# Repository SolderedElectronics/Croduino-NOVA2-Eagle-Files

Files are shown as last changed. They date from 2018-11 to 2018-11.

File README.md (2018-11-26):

# Croduino NOVA2 Eagle Files
## Image
Croduino NOVA2 image
[Croduino NOVA(222067)](https://e-radionica.com/en/croduino-nova2.html)

## Description and details
The Croduino NOVA2 is a microcontroller board with the ability to connect to a WiFi network and the Internet! It is based on an already well-known ESP8266 which is otherwise quite complicated to use on its own. With Nova, simply connect the board to USB and start programming your next IoT project. In addition, the microcontroller boards ideally suited for breadboard, which makes prototyping is even faster. Connecting the physical world with the internet has never been easier.

The brain of these boards is already mentioned Espressif's ESP826. Comes with full WiFi (both client and server side) and an integrated TCP / IP stack that supports DNS! Most importantly - programmable from Arduino IDE, there is no need to manually reset the board. The 80MHz frequency processor has as much as 1MB of space for your code (0.8MB available, bootloader 0.2MB) and 82kB of RAM (of which you can use 49kB). The board supports I2C, SPI and serial communications and has 9 GPIO pins, all of which support PWM and one analog input. In addition to the above, the board uses CH340 as a USB 2.0 interface, 3.3V voltage regulator, 4 LEDs, FCC and CE certificate, and a lot more. There is also an easyC connector on the board, which allows easy connection of various devices (available in e-radionica's offer) with a board. Finally, there is a standard JST lithium-ion connector for your project to be truly wireless. When you need to charge a battery, just plug in the USB cable and charge the battery with the integrated charger on the board. In detail:

- ESP8266 in ESP-12 package
- 80MHz, 1MB flash, 82kB RAM
- programmable from Arduina!
- 9 GPIO pins of which all support PWM
- 1 analog input(ADC), max. voltage 1V i 5V
- I2C, SPI, serial communication
- CH340 USB to UART bridge with micro USB connector
- 3.3V voltage regulator
- LEDs: power, tx, rx, GPIO13
- automatical hardware reset before upload of code
- two pushbuttons: reset i GPIO0
- comes with micro USB cable
- FCC i CE certificates for ESP-12

ESP8266 on-board is loaded with default bootloader.

## Repository content
This repo contains Cadsoft Eagle .sch and .brd files for Croduino NOVA board. It also contains schematic in .pdf created from .sch Eagle file. 
Files have been arranged into folders for navigating between different versions of board. 
Tip: layer 200 shows top silkscreen and layer 208 should be bottom silkscreen. tParts and bParts layers are not used.

## Docs
- [Croduino NOVA 2product page] (https://e-radionica.com/en/croduino-nova2.html)

## Board versions
- v1.0 - inital published version 

## License info
This product is open-source. Yay!
For any tech questions, contact us at techsupport@e-radionica.com
If you find an Issue, please open one at GitHub. If you can improve our product, fork us.

e-radionica.com Team.

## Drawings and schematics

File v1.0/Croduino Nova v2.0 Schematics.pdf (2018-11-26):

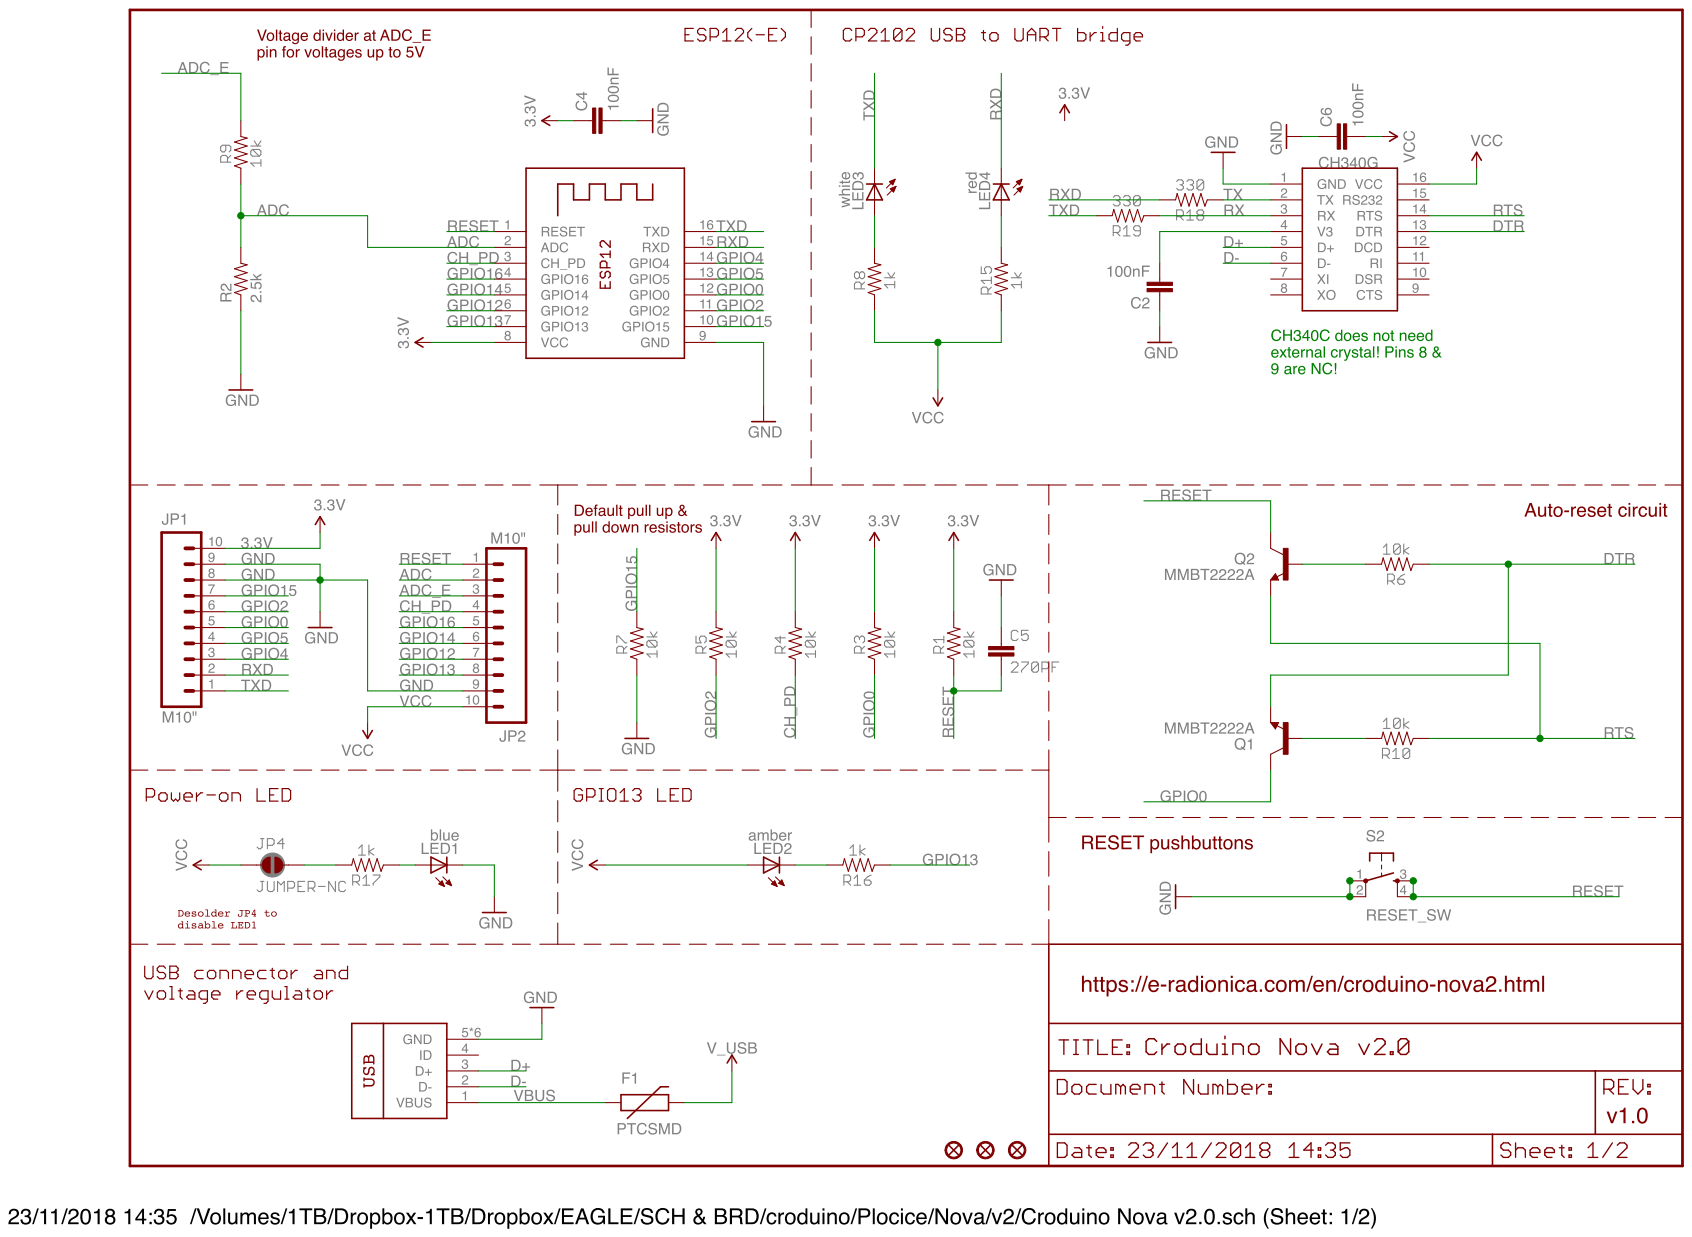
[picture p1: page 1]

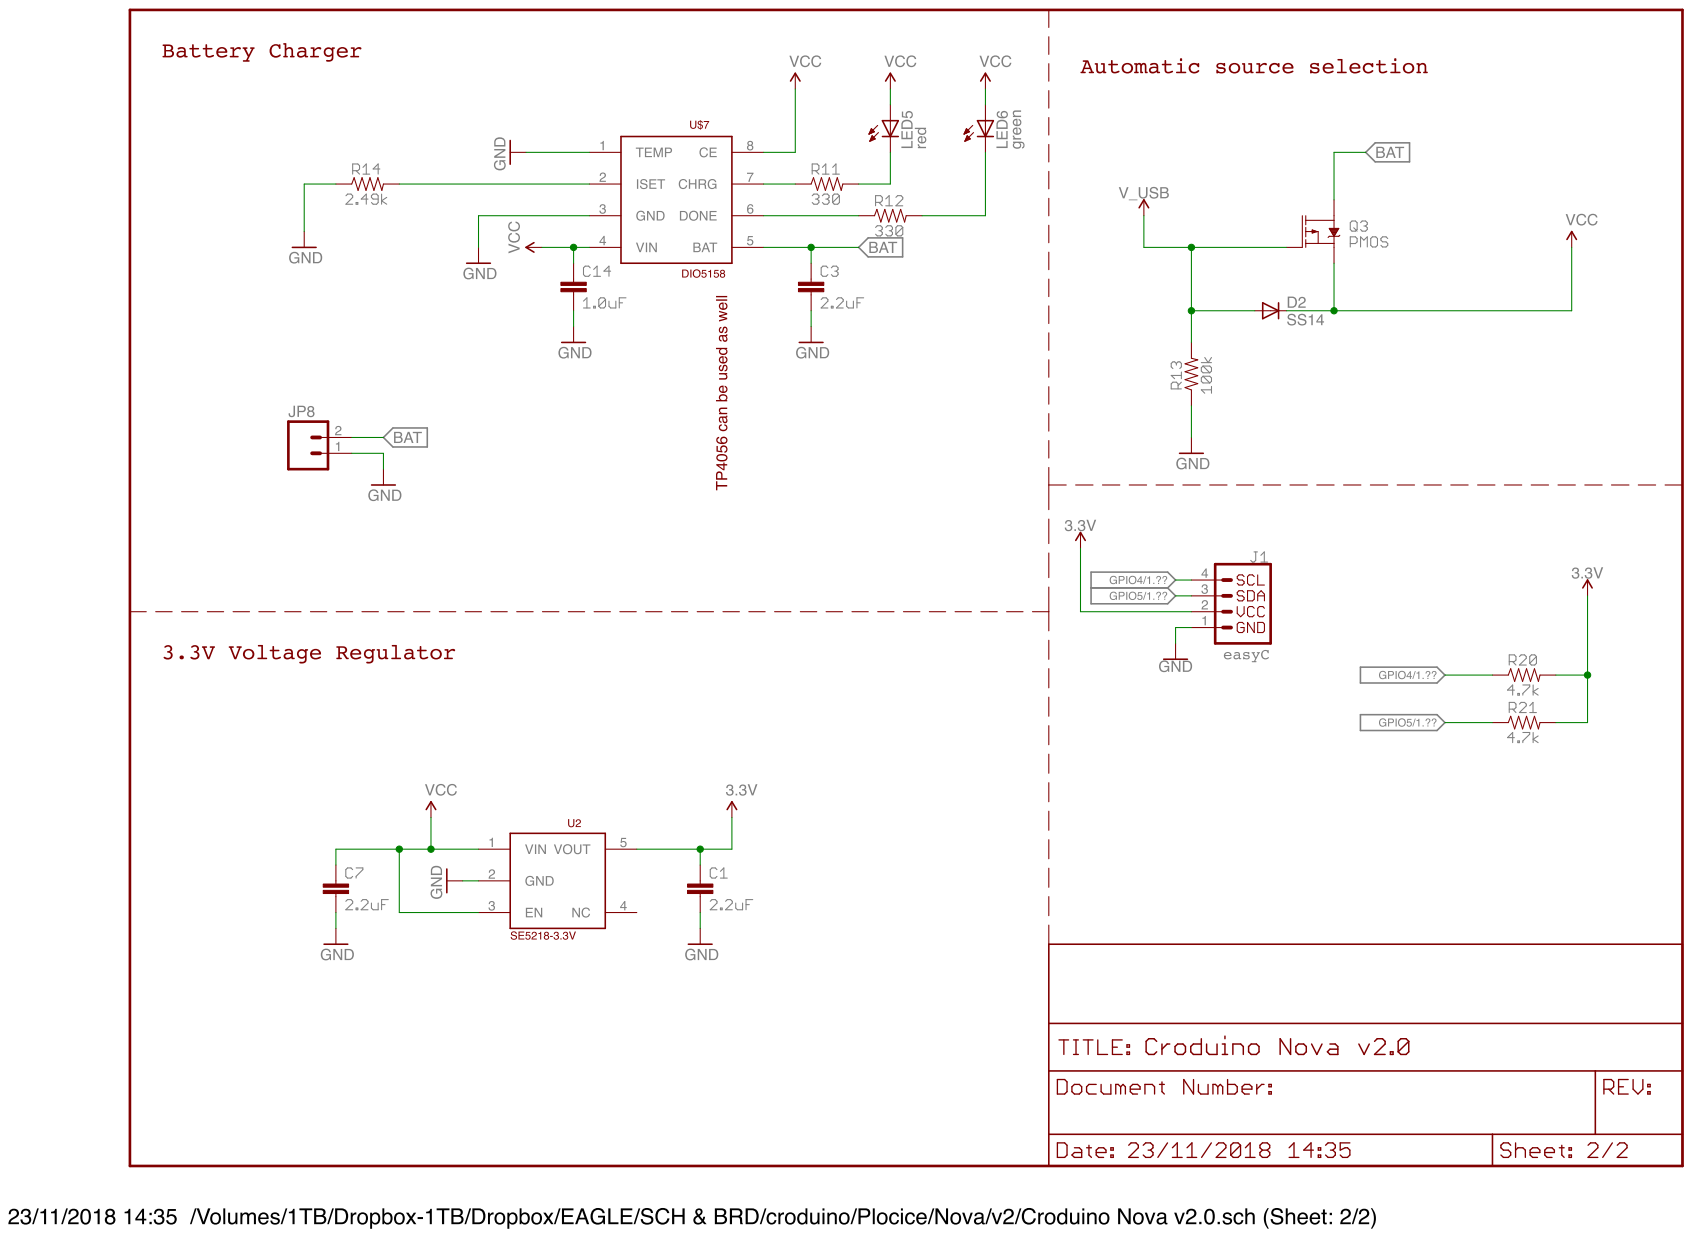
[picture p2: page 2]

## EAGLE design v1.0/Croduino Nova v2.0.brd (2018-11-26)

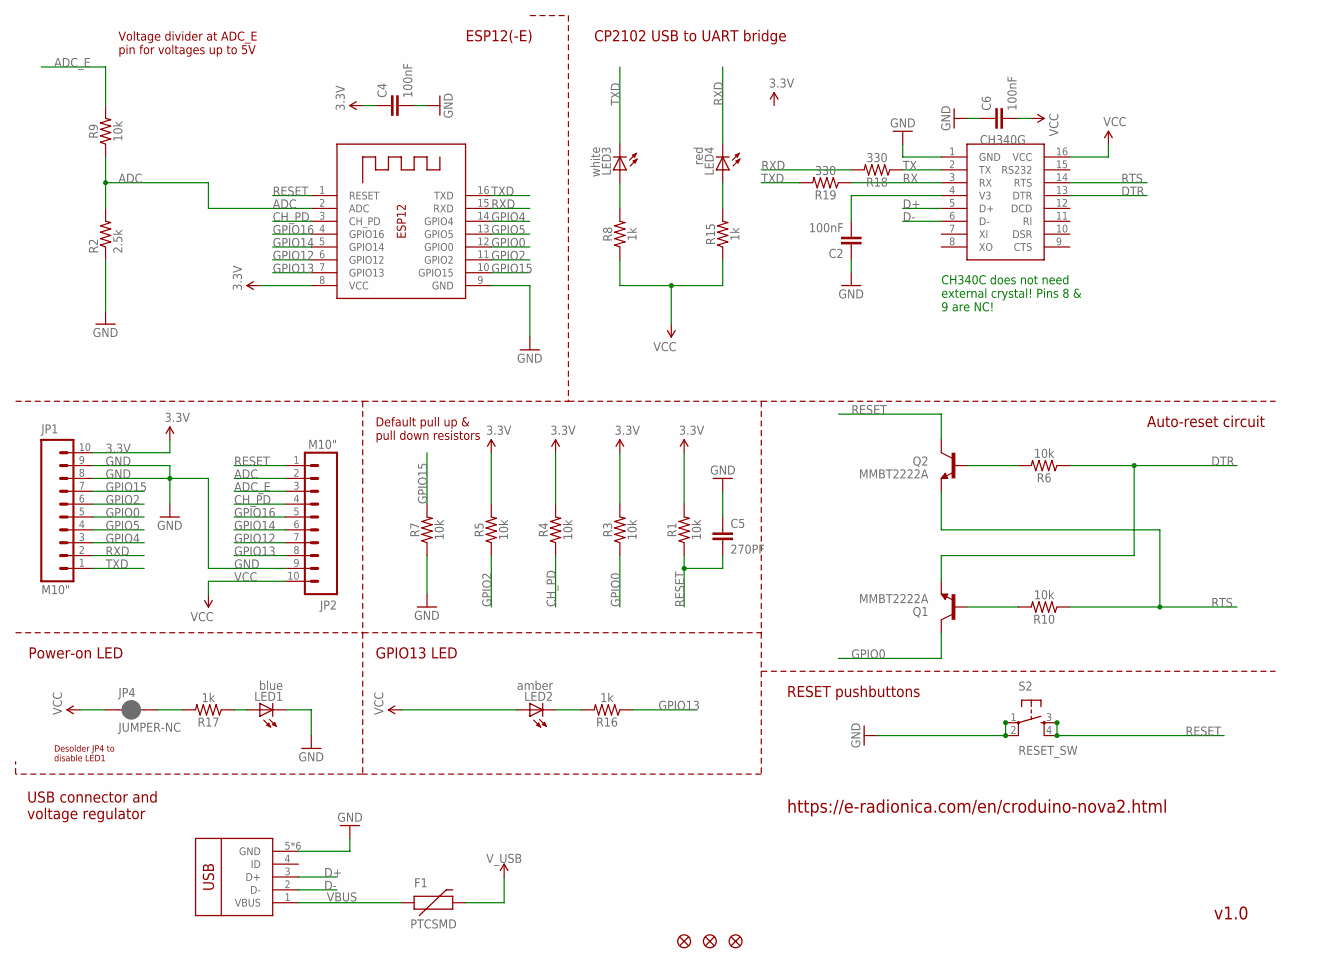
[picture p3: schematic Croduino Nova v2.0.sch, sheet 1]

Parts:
C2, C4, C6: 100nF; 0603-CAP
C5: 270PF; 0603
F1: PTCSMD; PTC-1206
JP1, JP2: M10"; 1X10
JP3, JP5, JP6: FIDUCIAL1X2; FIDUCIAL-1X2
JP4: JUMPER-NC; SMT-JUMPER_2_NC_PASTE_NO-SILK
LED1: blue; CHIP-LED0805
LED2: amber; CHIP-LED0805
LED3: white; CHIP-LED0805
LED4: red; CHIP-LED0805
Q1, Q2: MMBT2222A; SOT23-3
R1, R3, R4, R5, R6, R7, R9, R10: 10k; 0603
R2: 2.5k; 0603-RES
R8, R15, R16, R17: 1k; 0603
R18, R19: 330; 0603
S2: RESET_SW; TACTILE_SWITCH_SMD
U$8: USB-MICRO; U-F-M5DD-Y-L
U$10: CH340C; SOIC16
X1: ESP8266-12; ESP-12

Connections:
3.3V: C4.1, JP1.10, R1.2, R3.2, R4.2, R5.2, X1.8 (VCC); also elsewhere on the board
ADC: JP2.2, R2.2, R9.1, X1.2 (ADC)
ADC_E: JP2.3, R9.2
CH_PD: JP2.4, R4.1, X1.3 (CH_PD)
D+: U$8.3 (D+), U$10.5 (D+)
D-: U$8.2 (D-), U$10.6 (D-)
DTR: Q1.2 (E), R6.1, U$10.13 (DTR)
GND: C2.1, C4.2, C5.1, C6.1, JP1.8, JP1.9, JP2.9, LED1.C, R2.1, R7.1, S2.1, S2.2, U$8.5 (GND), U$8.PAD (GND), U$8.SHIELD1 (GND), U$8.SHIELD2 (GND), U$8.SHIELD3 (GND), U$8.SHIELD4 (GND), U$10.1 (GND), X1.9 (GND); also elsewhere on the board
GPIO0: JP1.5, Q1.3 (C), R3.1, X1.12 (GPIO0)
GPIO2: JP1.6, R5.1, X1.11 (GPIO2)
GPIO4: JP1.3, X1.14 (GPIO4); also elsewhere on the board
GPIO5: JP1.4, X1.13 (GPIO5); also elsewhere on the board
GPIO12: JP2.7, X1.6 (GPIO12)
GPIO13: JP2.8, R16.1, X1.7 (GPIO13)
GPIO14: JP2.6, X1.5 (GPIO14)
GPIO15: JP1.7, R7.2, X1.10 (GPIO15)
GPIO16: JP2.5, X1.4 (GPIO16)
unnamed: LED3.A, R8.2
unnamed: JP4.2, R17.2
unnamed: LED1.A, R17.1
unnamed: LED4.A, R15.2
unnamed: LED2.C, R16.2
unnamed: C2.2, U$10.4 (V3)
unnamed: Q1.1 (B), R10.2
unnamed: Q2.1 (B), R6.2
RESET: C5.2, JP2.1, Q2.3 (C), R1.1, S2.3, S2.4, X1.1 (RESET)
RTS: Q2.2 (E), R10.1, U$10.14 (RTS)
RX: R19.1, U$10.3 (RX)
RXD: JP1.2, LED4.C, R18.2, X1.15 (RXD)
TX: R18.1, U$10.2 (TX)
TXD: JP1.1, LED3.C, R19.2, X1.16 (TXD)
VBUS: F1.1, U$8.1 (VBUS)
VCC: C6.2, JP2.10, JP4.1, LED2.A, R8.1, R15.1, U$10.16 (VCC); also elsewhere on the board
V_USB: F1.2; also elsewhere on the board

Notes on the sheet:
USB connector and voltage regulator
Power-on LED
GPIO13 LED
Desolder JP4 to disable LED1
ESP12(-E)
CP2102 USB to UART bridge
Voltage divider at ADC_E pin for voltages up to 5V
Default pull up & pull down resistors
Auto-reset circuit
RESET pushbuttons
https://e-radionica.com/en/croduino-nova2.html
v1.0
CH340C does not need external crystal! Pins 8 & 9 are NC!

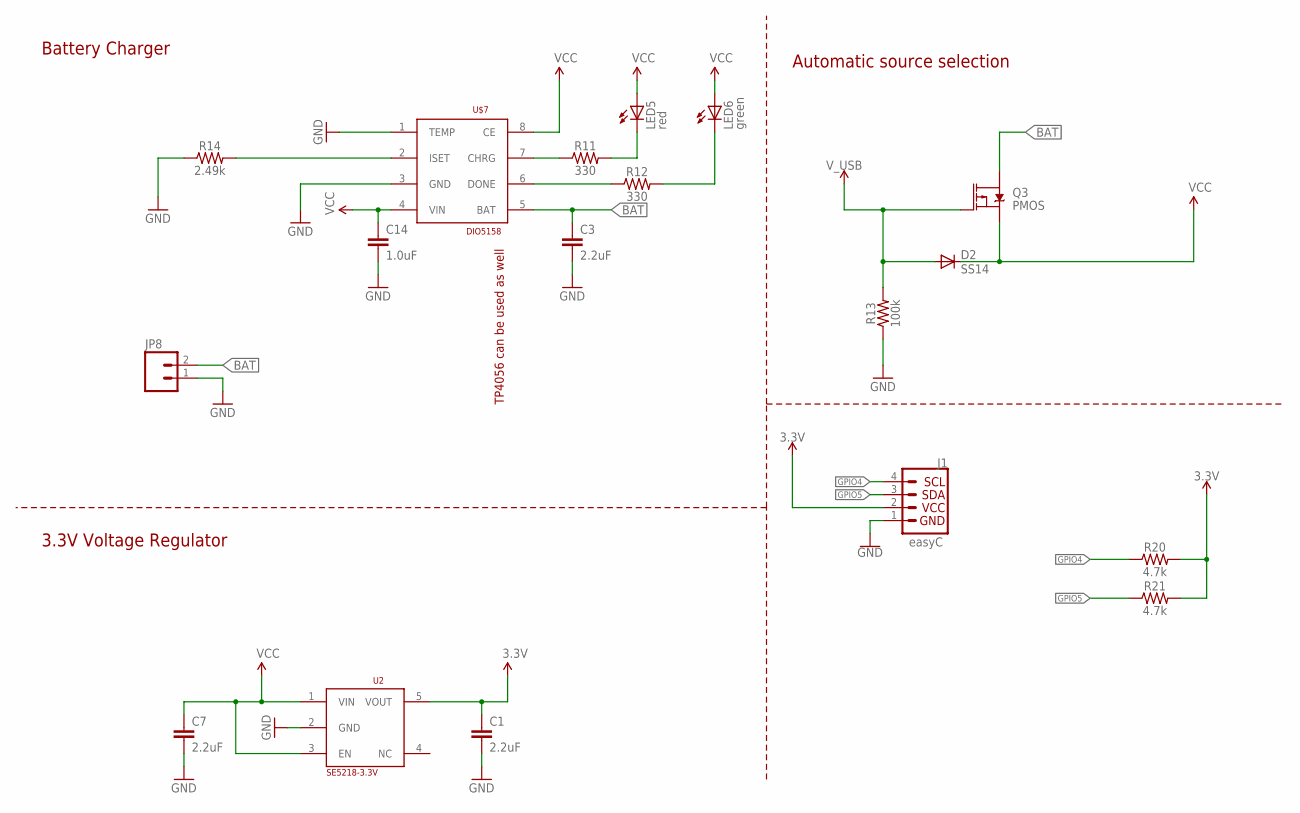
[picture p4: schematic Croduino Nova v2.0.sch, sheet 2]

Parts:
C1, C3, C7: 2.2uF; 0603
C14: 1.0uF; 0603
D2: SS14; DO-214AC
J1: QWIIC_CONNECTORJS-1MM; 1X04_1MM_RA
JP8: M02-JST-2MM-SMT; JST-2-SMD
LED5: red; CHIP-LED0805
LED6: green; CHIP-LED0805
Q3: PMOS; SOT23-3
R11, R12: 330; 0603
R13: 100k; 0603
R14: 2.49k; 0603
R20, R21: 4.7k; 0603
U2: SE5218-3.3V; SOT23-5
U$7: DIO5158; SOIC-8

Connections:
3.3V: C1.1, J1.2, R20.2, R21.2, U2.5 (VOUT); also elsewhere on the board
BAT: C3.1, JP8.2, Q3.3 (D), U$7.5 (BAT)
CHRG: R11.1, U$7.7 (CHRG)
DONE: R12.1, U$7.6 (DONE)
GND: C1.2, C3.2, C7.2, C14.2, J1.1, JP8.1, R13.1, R14.1, U2.2 (GND), U$7.1 (TEMP), U$7.3 (GND); also elsewhere on the board
GPIO4: J1.4, R20.1; also elsewhere on the board
GPIO5: J1.3, R21.1; also elsewhere on the board
ISET: R14.2, U$7.2 (ISET)
LED1: LED5.C, R11.2
LED2: LED6.C, R12.2
VCC: C7.1, C14.1, D2.C, LED5.A, LED6.A, Q3.2 (S), U2.1 (VIN), U2.3 (EN), U$7.4 (VIN), U$7.8 (CE); also elsewhere on the board
V_USB: D2.A, Q3.1 (G), R13.2; also elsewhere on the board

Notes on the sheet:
TP4056 can be used as well
3.3V Voltage Regulator
Battery Charger
Automatic source selection
easyC

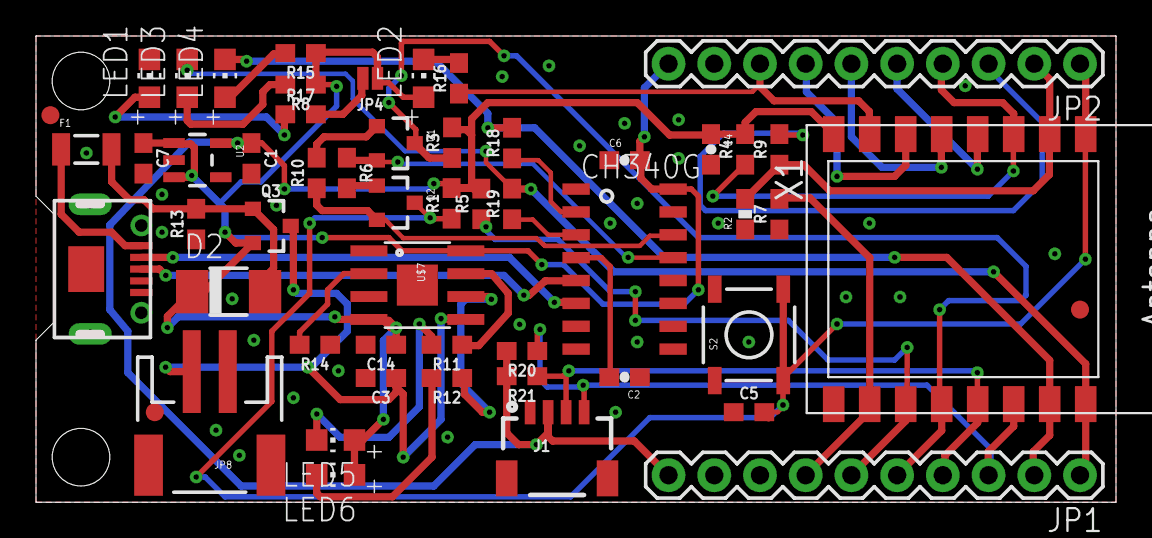
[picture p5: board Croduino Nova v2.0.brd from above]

Board: 2 copper layers, 60.0 x 25.9 mm, 60 parts (0 on the bottom side), 40 nets.

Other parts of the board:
U$1: LOGO-3MM
U$3: OSH-3MM
U$4: E-R.IO-6MM
U$5: MADE-IN-CROATIA-10MM
U$6: EASYC
U$9: CRODUINO_NOVA_V2.0

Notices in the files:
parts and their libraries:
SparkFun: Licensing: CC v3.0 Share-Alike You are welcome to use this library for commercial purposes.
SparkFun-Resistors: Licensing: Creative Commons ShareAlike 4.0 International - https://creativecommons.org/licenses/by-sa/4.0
